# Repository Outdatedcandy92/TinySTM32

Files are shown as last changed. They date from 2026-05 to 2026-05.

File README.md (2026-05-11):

# TinySTM32

TinySTM32 is a small 30mmx30mm devboard that features a STM32F103T8U6. It has two programmable buttons and LEDs on board, and 18 pins broken out.

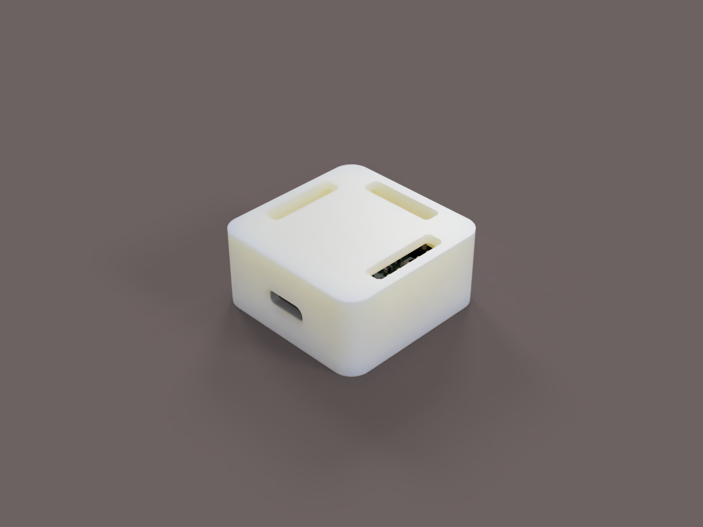
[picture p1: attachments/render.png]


## Hardware

[KiCanvas Link](https://kicanvas.org/?repo=https%3A%2F%2Fgithub.com%2FOutdatedcandy92%2FTinySTM32%2Ftree%2Fmain%2Fkicad)
### Schematic

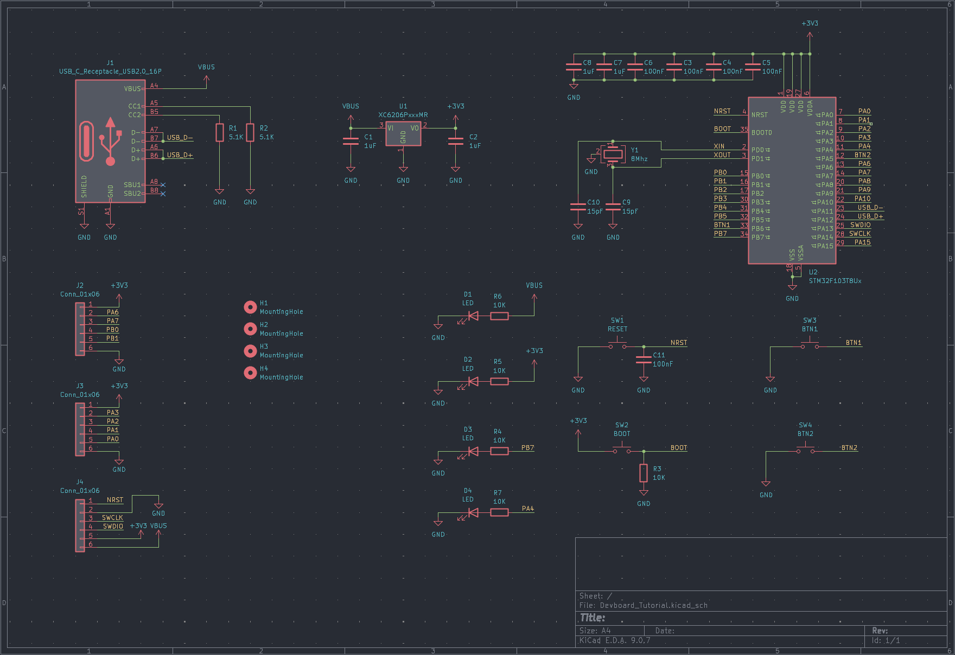
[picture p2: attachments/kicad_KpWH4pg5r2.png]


### PCB

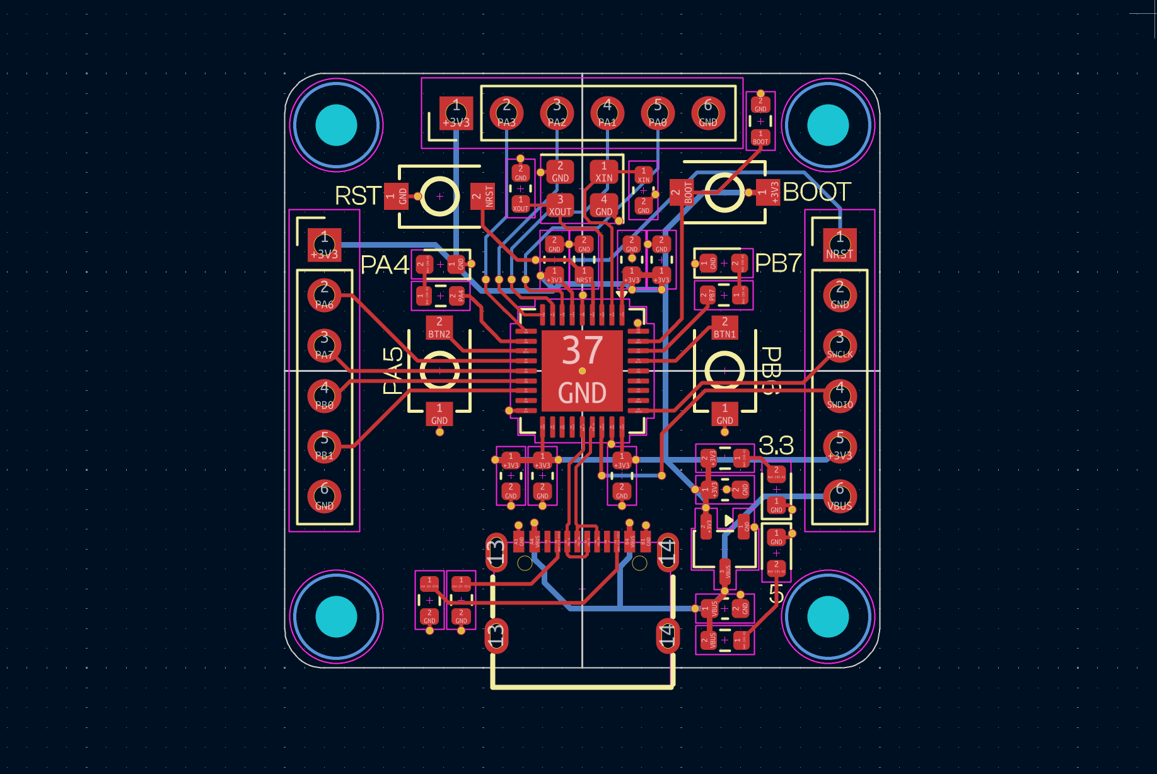
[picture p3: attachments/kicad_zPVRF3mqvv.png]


### 3D PCB

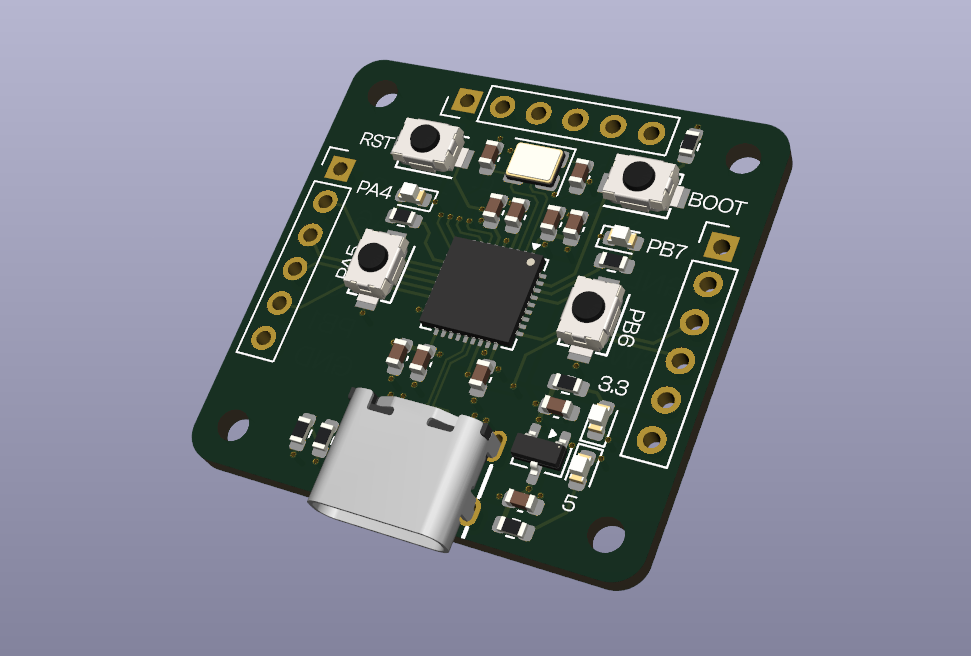
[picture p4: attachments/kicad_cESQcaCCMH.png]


### Case

The case uses M2 screws to mount the PCB.

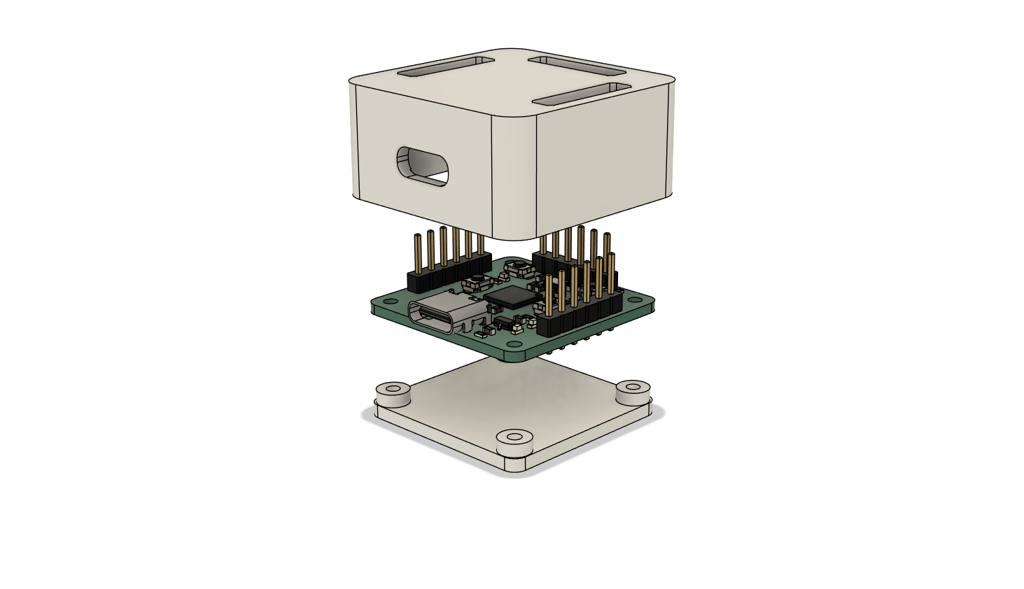
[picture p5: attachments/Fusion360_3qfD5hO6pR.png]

## License

This project is licensed under the CERN Open Hardware Licence Version 2 Weakly Reciprocal [(CERN OHL W)](LICENSE.txt)

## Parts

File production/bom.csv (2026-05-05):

Designator | Footprint | Quantity | Value | LCSC Part #
C1, C2, C7, C8 | 0603 | 4 | 1uF
C10, C9 | 0603 | 2 | 15pF
C11, C3, C4, C5, C6 | 0603 | 5 | 100nF
D1, D2, D3, D4 | 0603 | 4 | LED
J1 | USB-C-SMD_TYPE-C-16PIN-2MD-073 | 1 | USB_C_Receptacle_USB2.0_16P | C2765186
J2, J3, J4 | PinHeader_1x06_P2.54mm_Vertical | 3 | Conn_01x06
R1, R2 | 0603 | 2 | 5.1K
R3, R4, R5, R6, R7 | 0603 | 5 | 10K
SW1 | SW-SMD_L3.9-W3.0-P4.45 | 1 | RESET
SW2 | SW-SMD_L3.9-W3.0-P4.45 | 1 | BOOT
SW3 | SW-SMD_L3.9-W3.0-P4.45 | 1 | BTN1
SW4 | SW-SMD_L3.9-W3.0-P4.45 | 1 | BTN2
U1 | SOT-23-3 | 1 | XC6206PxxxMR
U2 | QFN-36-1EP_6x6mm_P0.5mm_EP4.1x4.1mm | 1 | STM32F103T8Ux
Y1 | Crystal_SMD_3225-4Pin_3.2x2.5mm | 1 | 8Mhz

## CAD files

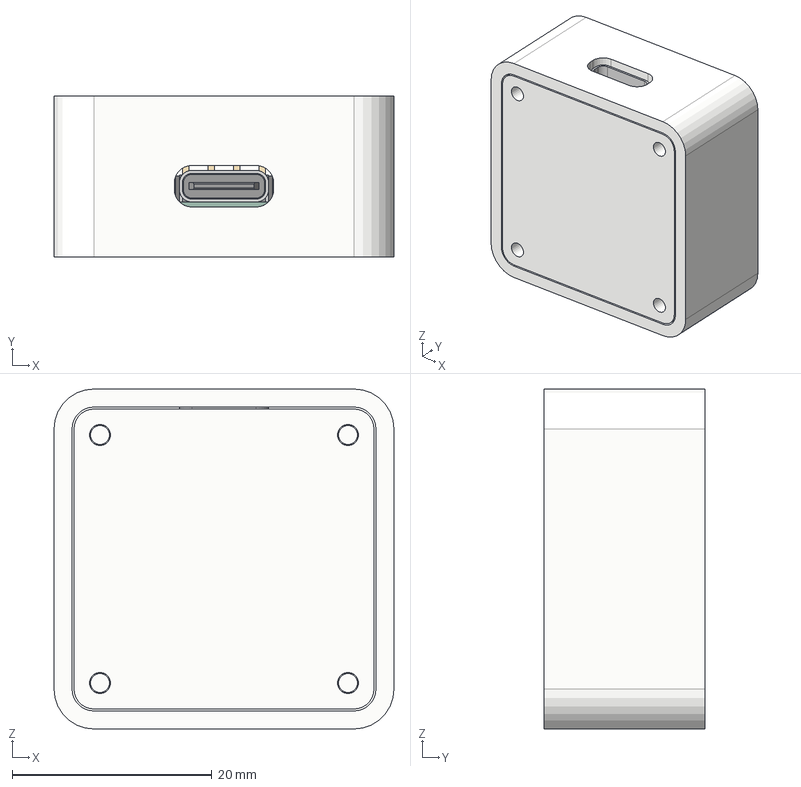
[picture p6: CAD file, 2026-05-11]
Case.step
34.0 x 16.1 x 34.0 mm
R_0603_1608Metric x 7
LED_0603_1608Metric x 4
PinHeader_1x06_P2.54mm_Vertical x 3
SW-SMD_L3.9-W2.9-H2.0-LS4.8 x 4
C_0603_1608Metric x 11
USB-C-SMD_TYPE-C-6PIN-2MD-073
SOT-23-3
QFN-36-1EP_6x6mm_P0.5mm_EP3.7x3.7mm
Crystal_SMD_3225-4Pin_3.2x2.5mm
Devboard_Tutorial_PCB

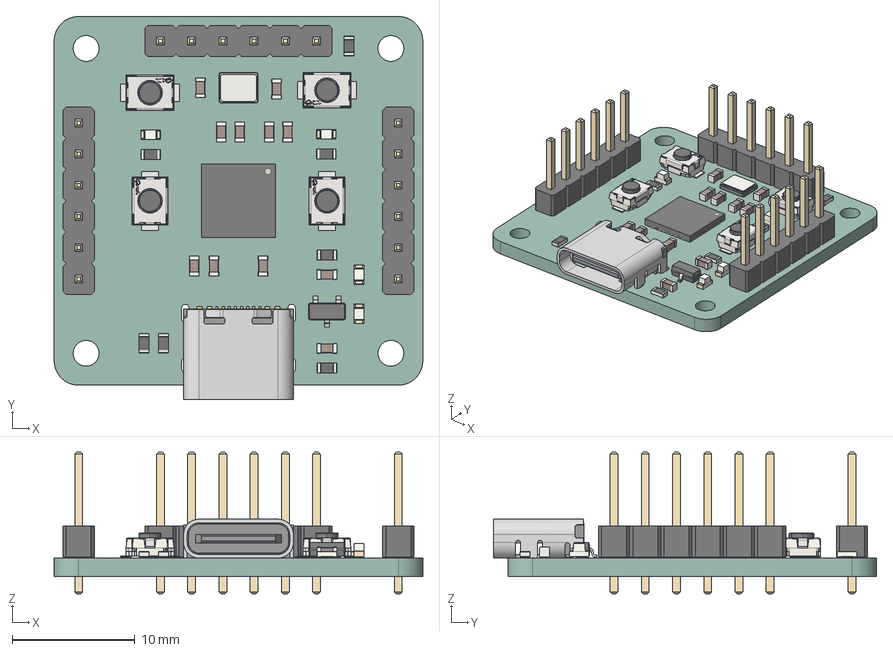
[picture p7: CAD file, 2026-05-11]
kicad/Devboard_Tutorial.step
30.0 x 31.2 x 11.5 mm
R_0603_1608Metric x 7
LED_0603_1608Metric x 4
PinHeader_1x06_P2.54mm_Vertical x 3
SW-SMD_L3.9-W2.9-H2.0-LS4.8 x 4
C_0603_1608Metric x 11
USB-C-SMD_TYPE-C-6PIN-2MD-073
SOT-23-3
QFN-36-1EP_6x6mm_P0.5mm_EP3.7x3.7mm
Crystal_SMD_3225-4Pin_3.2x2.5mm
Devboard_Tutorial_PCB

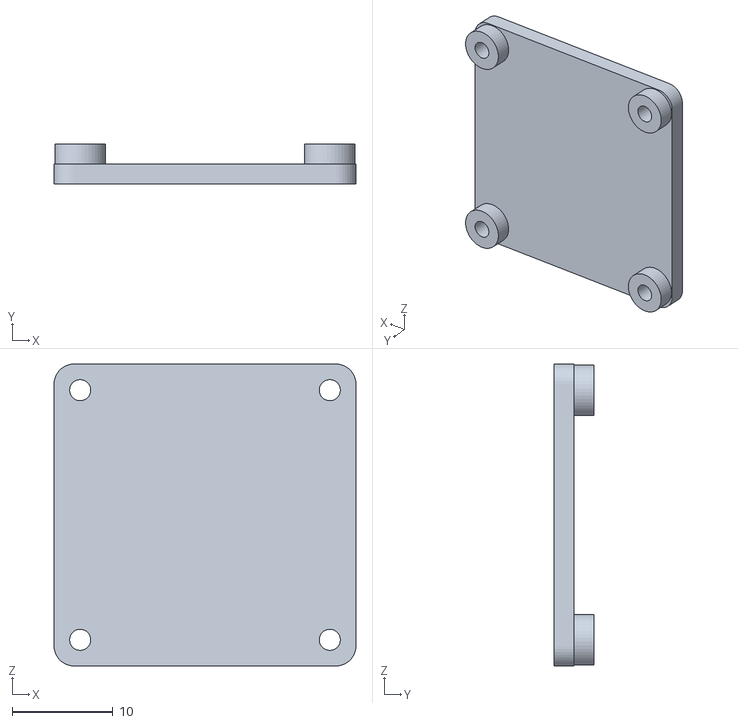
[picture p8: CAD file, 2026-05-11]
production/case_bottom.stl
30.0 x 4.00 x 30.0

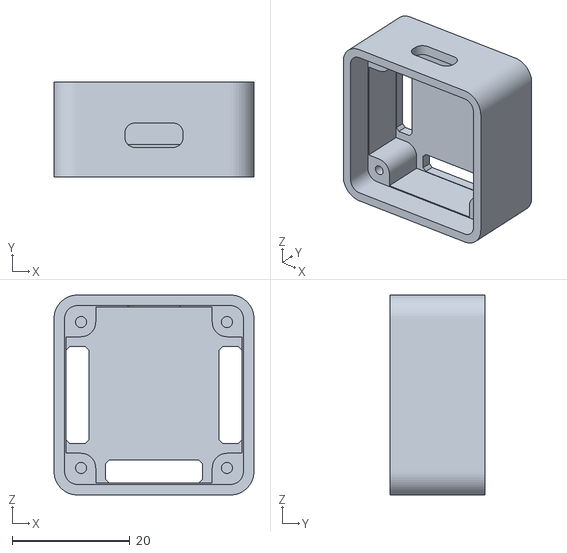
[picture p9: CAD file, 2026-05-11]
production/case_top.stl
34.0 x 16.1 x 34.0

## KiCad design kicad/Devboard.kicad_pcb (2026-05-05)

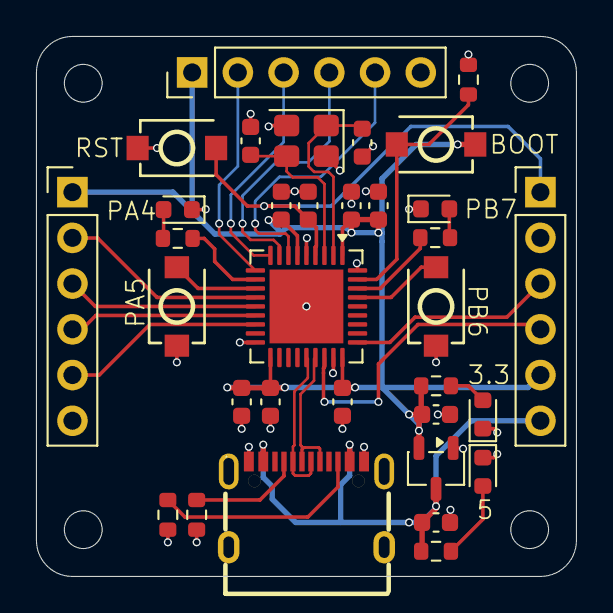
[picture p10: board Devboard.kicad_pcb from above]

Board: 4 copper layers, 30.0 x 30.0 mm, 37 parts (0 on the bottom side), 29 nets.

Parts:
C1, C2, C7, C8: 1uF; C_0603_1608Metric
C3, C4, C5, C6, C11: 100nF; C_0603_1608Metric
C9, C10: 15pF; C_0603_1608Metric
D1, D2, D3, D4: LED; LED_0603_1608Metric
H1, H2, H3, H4: MountingHole; MountingHole_2.1mm
J1: USB_C_Receptacle_USB2.0_16P; USB-C-SMD_TYPE-C-16PIN-2MD-073
J2, J3, J4: Conn_01x06; PinHeader_1x06_P2.54mm_Vertical
R1, R2: 5.1K; R_0603_1608Metric
R3, R4, R5, R6, R7: 10K; R_0603_1608Metric
SW1: RESET; SW-SMD_L3.9-W3.0-P4.45
SW2: BOOT; SW-SMD_L3.9-W3.0-P4.45
SW3: BTN1; SW-SMD_L3.9-W3.0-P4.45
SW4: BTN2; SW-SMD_L3.9-W3.0-P4.45
U1: XC6206PxxxMR; SOT-23-3
U2: STM32F103T8Ux; QFN-36-1EP_6x6mm_P0.5mm_EP4.1x4.1mm
Y1: 8Mhz; Crystal_SMD_3225-4Pin_3.2x2.5mm

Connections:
+3V3: C2.1, C3.1, C4.1, C5.1, C6.1, C7.1, C8.1, J2.1, J3.1, J4.5, R5.2, SW2.1, U1.2 (VO), U2.1 (VDD), U2.6 (VDDA), U2.19 (VDD), U2.27 (VDD)
/BOOT: R3.1, SW2.2, U2.35 (BOOT0)
/BTN1: SW3.2, U2.33 (PB6)
/BTN2: SW4.2, U2.12 (PA5)
/NRST: C11.1, J4.1, SW1.2, U2.4 (NRST)
/PA0: J3.5, U2.7 (PA0)
/PA1: J3.4, U2.8 (PA1)
/PA2: J3.3, U2.9 (PA2)
/PA3: J3.2, U2.10 (PA3)
/PA4: R7.2, U2.11 (PA4)
/PA6: J2.2, U2.13 (PA6)
/PA7: J2.3, U2.14 (PA7)
/PB0: J2.4, U2.15 (PB0)
/PB1: J2.5, U2.16 (PB1)
/PB7: R4.2, U2.34 (PB7)
/SWCLK: J4.3, U2.28 (PA14)
/SWDIO: J4.4, U2.25 (PA13)
/USB_D+: J1.A6 (D+), J1.B6 (D+), U2.24 (PA12)
/USB_D-: J1.A7 (D-), J1.B7 (D-), U2.23 (PA11)
/XIN: C10.1, U2.2 (PD0), Y1.1
/XOUT: C9.1, U2.3 (PD1), Y1.3
GND: C1.2, C2.2, C3.2, C4.2, C5.2, C6.2, C7.2, C8.2, C9.2, C10.2, C11.2, D1.1 (K), D2.1 (K), D3.1 (K), D4.1 (K), J1.A1 (GND), J1.B1 (GND), J2.6, J3.6, J4.2, R1.2, R2.2, R3.2, SW1.1, SW3.1, SW4.1, U1.1 (GND), U2.5 (VSSA), U2.18 (VSS), U2.26 (VSS), U2.36 (VSS), U2.37 (VSS), Y1.2 (G), Y1.4 (G)
unnamed: D1.2 (A), R6.1
unnamed: D2.2 (A), R5.1
unnamed: D3.2 (A), R4.1
unnamed: D4.2 (A), R7.1
unnamed: J1.A5 (CC1), R2.1
unnamed: J1.B5 (CC2), R1.1
VBUS: C1.1, J1.A4 (VBUS), J1.B4 (VBUS), J4.6, R6.2, U1.3 (VI)
